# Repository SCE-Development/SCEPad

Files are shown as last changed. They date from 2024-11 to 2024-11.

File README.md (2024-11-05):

<p align="center" style = "font-size:48px;" >SCEPad</p>

<div align="center"

[]()
[]()
[]()
[]()
[]()

</div>

## General Description 
The SCE Pad is a instructional tool used during our soldering workshop series.

## Table of Contents
- Bill of Materials
- Firmware Flashing
- Assembly Instructions 

## Bill of Materials
| Qty | Item | Notes
| ---- | ---- | ---- |
| 1 | Arduino Pro Micro (ATmega32u4) | Alternatively you can use the [Elite-C](https://keeb.io/products/elite-c-low-profile-version-usb-c-pro-micro-replacement-atmega32u4) or [Nice!Nano](https://nicekeyboards.com/nice-nano/)|
| 18  | Cherry MX compatible swtiches | |
| 18  | SOD-123 1N4148/1N4148W diodes | |
| 18  | Kailh PCB sockets CPG151101S11 | |
| 9 | WS2812B RGB LEDs | |
| 9 | SMD 0805 100nF capacitors | |
| 1 | I2C 0.91" 128\*32 OLED Display Module | The ones using SSD1306 driver IC over I2C |
| 1 | 6mm\*6mm button switch | |
| 1 | SCEPad PCB | Available in SCE Club Room (ENG294) |
| 5 | M3 screws | |

## Firmware Flashing

Requirements
- [QMK Toolbox](https://github.com/qmk/qmk_toolbox)

After installing QMK toolbox, assuming you are using the default ProMicro controller, plug the device into your computer and you should see it show up as a new device in the console. Make sure the MCU selected is an ATmega32U4. Auto-flash is useful here but its preference. 

Select your hex-file and flash your microcontroller.

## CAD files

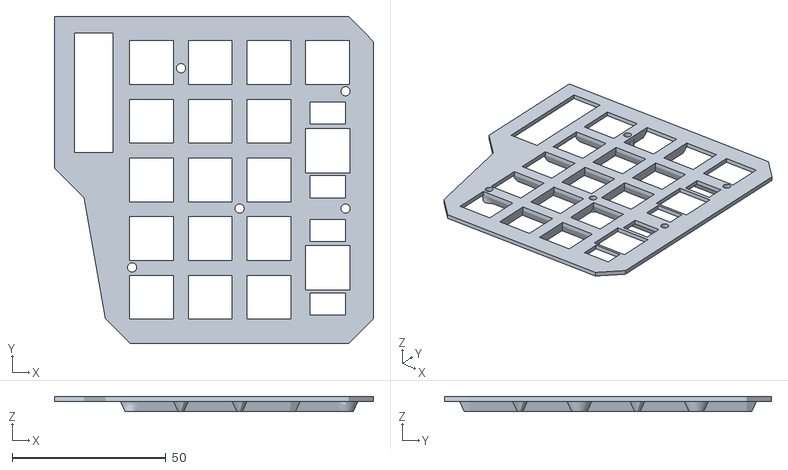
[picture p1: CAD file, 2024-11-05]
Case/SCEPAD Mounting Plate.stl
103.6 x 106.2 x 4.80

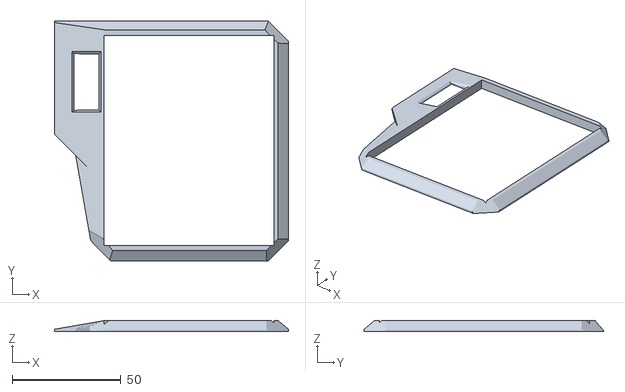
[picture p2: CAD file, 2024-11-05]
Case/SCEPAD Top Plate.stl
107.4 x 110.0 x 5.00

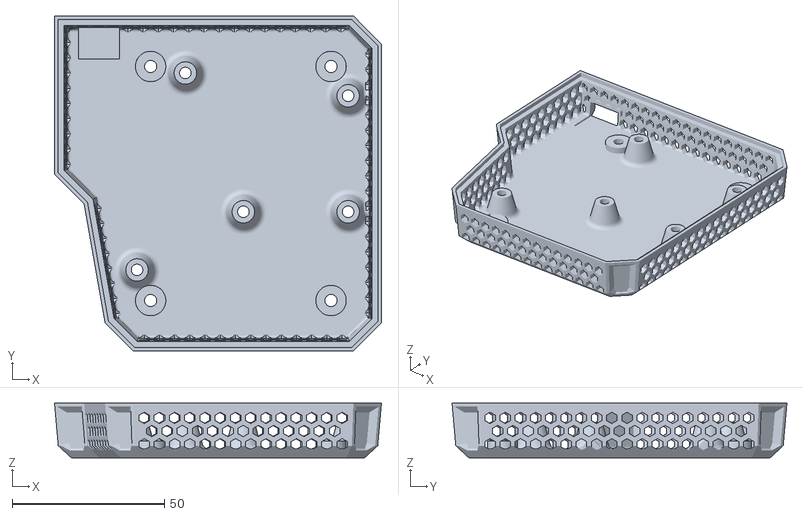
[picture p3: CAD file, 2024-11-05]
Case/SCEPAD Number Pad.stl
107.4 x 110.0 x 18.0

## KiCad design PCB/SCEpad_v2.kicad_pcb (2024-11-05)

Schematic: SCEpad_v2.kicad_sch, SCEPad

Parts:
C0, C1, C2, C3, C4, C5, C6, C7, C8: 104; C_0805_2012Metric_Pad1.15x1.40mm_HandSolder
D0, D1, D2, D3, D10, D11, D12, D13, D20, D21, D22, D30, D31, D32, D40, D41, D42, D43: D; D_SOD123_axial-dual
JOLED1: Conn_01x04; PinHeader_1x04_P2.54mm_Horizontal
K0, K1, K2, K3, K10, K11, K12, K13, K20, K21, K22, K30, K31, K32, K40, K41, K42, K43: KEYSW; Kailh-PCB-Socket-1U-Cutout
LED0, LED1, LED2, LED3, LED4, LED5, LED6, LED7, LED8: WS2812B; LED_WS2812B_PLCC4_5.0x5.0mm_P3.2mm
SW0: SW_Push; SW_PUSH_6mm
U0: ProMicro; ArduinoProMicro

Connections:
COL0: K0.1, K10.1, K20.1, K30.1, K40.1, U0.16
COL1: K1.1, K11.1, K21.1, K31.1, K41.1, U0.15
COL2: K2.1, K12.1, K22.1, K32.1, K42.1, U0.14
COL3: K3.1, K13.1, K43.1, U0.13
GND: C0.1, C1.1, C2.1, C3.1, C4.1, C5.1, C6.1, C7.1, C8.1, JOLED1.4, LED0.3 (VSS), LED1.3 (VSS), LED2.3 (VSS), LED3.3 (VSS), LED4.3 (VSS), LED5.3 (VSS), LED6.3 (VSS), LED7.3 (VSS), LED8.3 (VSS), SW0.1, U0.3, U0.4, U0.23; also elsewhere on the board
LEDs: LED0.4 (DIN), U0.20
unnamed: D0.2 (A), K0.2
unnamed: D1.2 (A), K1.2
unnamed: D2.2 (A), K2.2
unnamed: D3.2 (A), K3.2
unnamed: D10.2 (A), K10.2
unnamed: D11.2 (A), K11.2
unnamed: D12.2 (A), K12.2
unnamed: D13.2 (A), K13.2
unnamed: D20.2 (A), K20.2
unnamed: D21.2 (A), K21.2
unnamed: D22.2 (A), K22.2
unnamed: D30.2 (A), K30.2
unnamed: D31.2 (A), K31.2
unnamed: D32.2 (A), K32.2
unnamed: D40.2 (A), K40.2
unnamed: D41.2 (A), K41.2
unnamed: D42.2 (A), K42.2
unnamed: D43.2 (A), K43.2
unnamed: LED0.2 (DOUT), LED1.4 (DIN)
unnamed: LED1.2 (DOUT), LED2.4 (DIN)
unnamed: LED2.2 (DOUT), LED3.4 (DIN)
unnamed: LED3.2 (DOUT), LED4.4 (DIN)
unnamed: LED4.2 (DOUT), LED5.4 (DIN)
unnamed: LED5.2 (DOUT), LED6.4 (DIN)
unnamed: LED6.2 (DOUT), LED7.4 (DIN)
unnamed: LED7.2 (DOUT), LED8.4 (DIN)
PF7: U0.17
ROW0: D0.1 (K), D1.1 (K), D2.1 (K), D3.1 (K), U0.8
ROW1: D10.1 (K), D11.1 (K), D12.1 (K), D13.1 (K), U0.9
ROW2: D20.1 (K), D21.1 (K), D22.1 (K), U0.10
ROW3: D30.1 (K), D31.1 (K), D32.1 (K), U0.11
ROW4: D40.1 (K), D41.1 (K), D42.1 (K), D43.1 (K), U0.12
RST: U0.22; also elsewhere on the board
SCL: U0.6; also elsewhere on the board
SDA: U0.5; also elsewhere on the board
VCC: C0.2, C1.2, C2.2, C3.2, C4.2, C5.2, C6.2, C7.2, C8.2, JOLED1.3, LED0.1 (VDD), LED1.1 (VDD), LED2.1 (VDD), LED3.1 (VDD), LED4.1 (VDD), LED5.1 (VDD), LED6.1 (VDD), LED7.1 (VDD), LED8.1 (VDD), U0.21; also elsewhere on the board

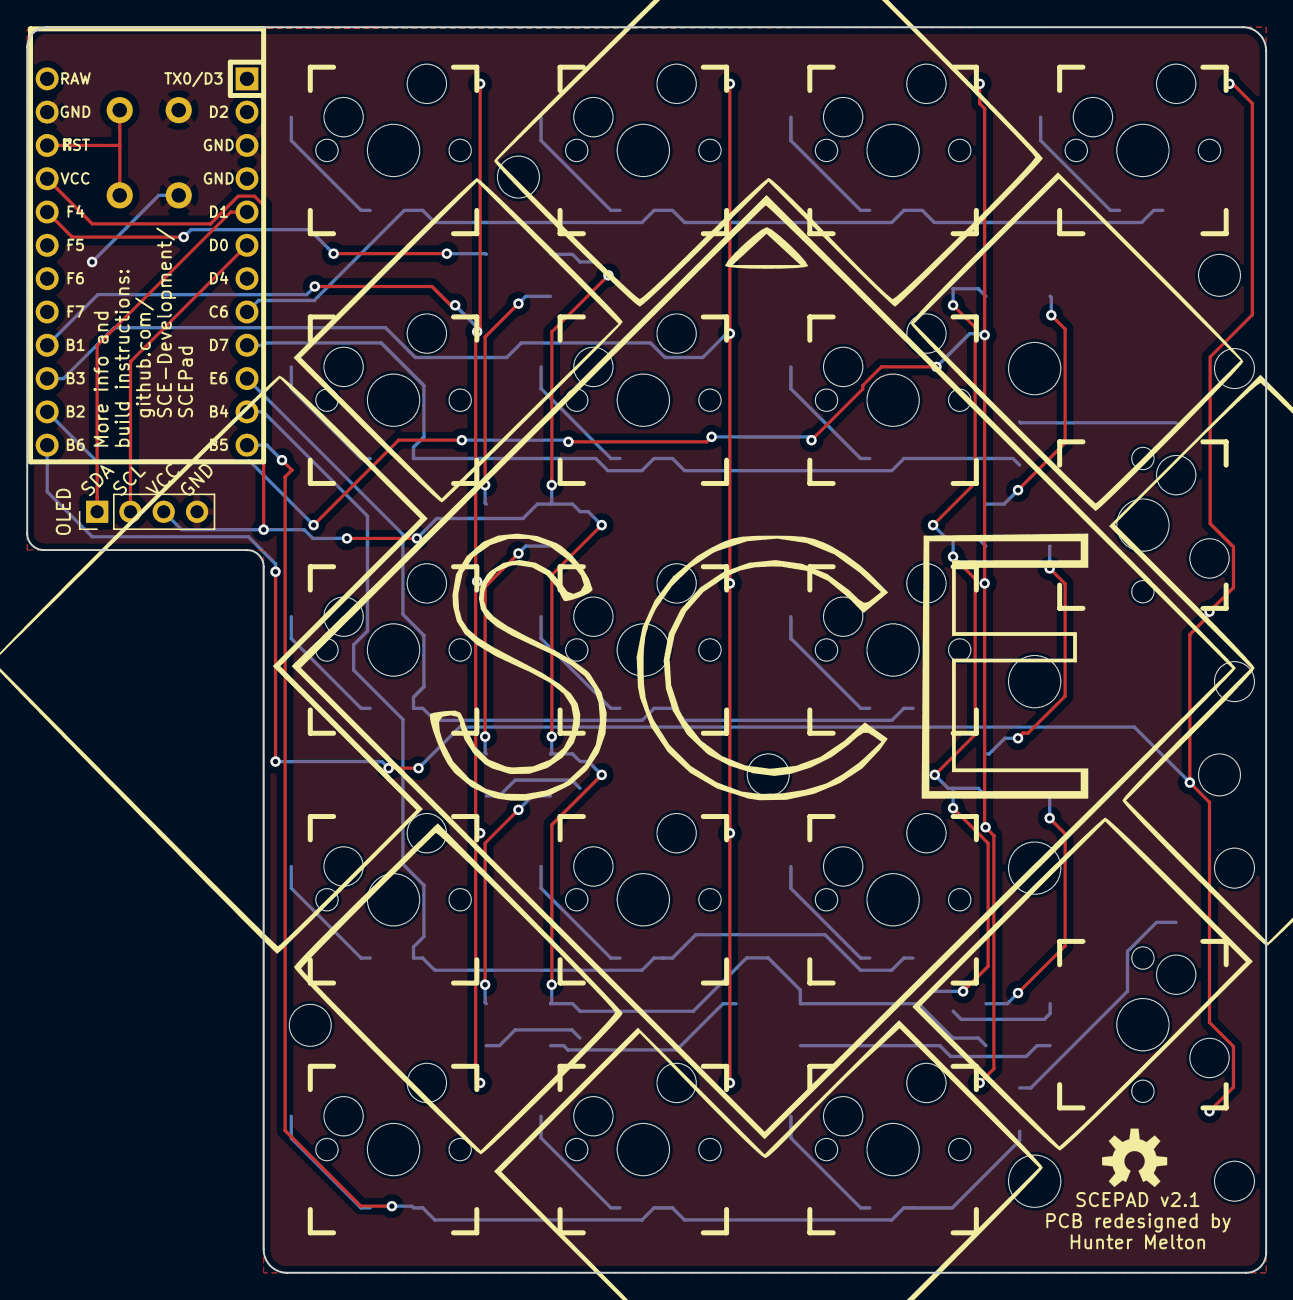
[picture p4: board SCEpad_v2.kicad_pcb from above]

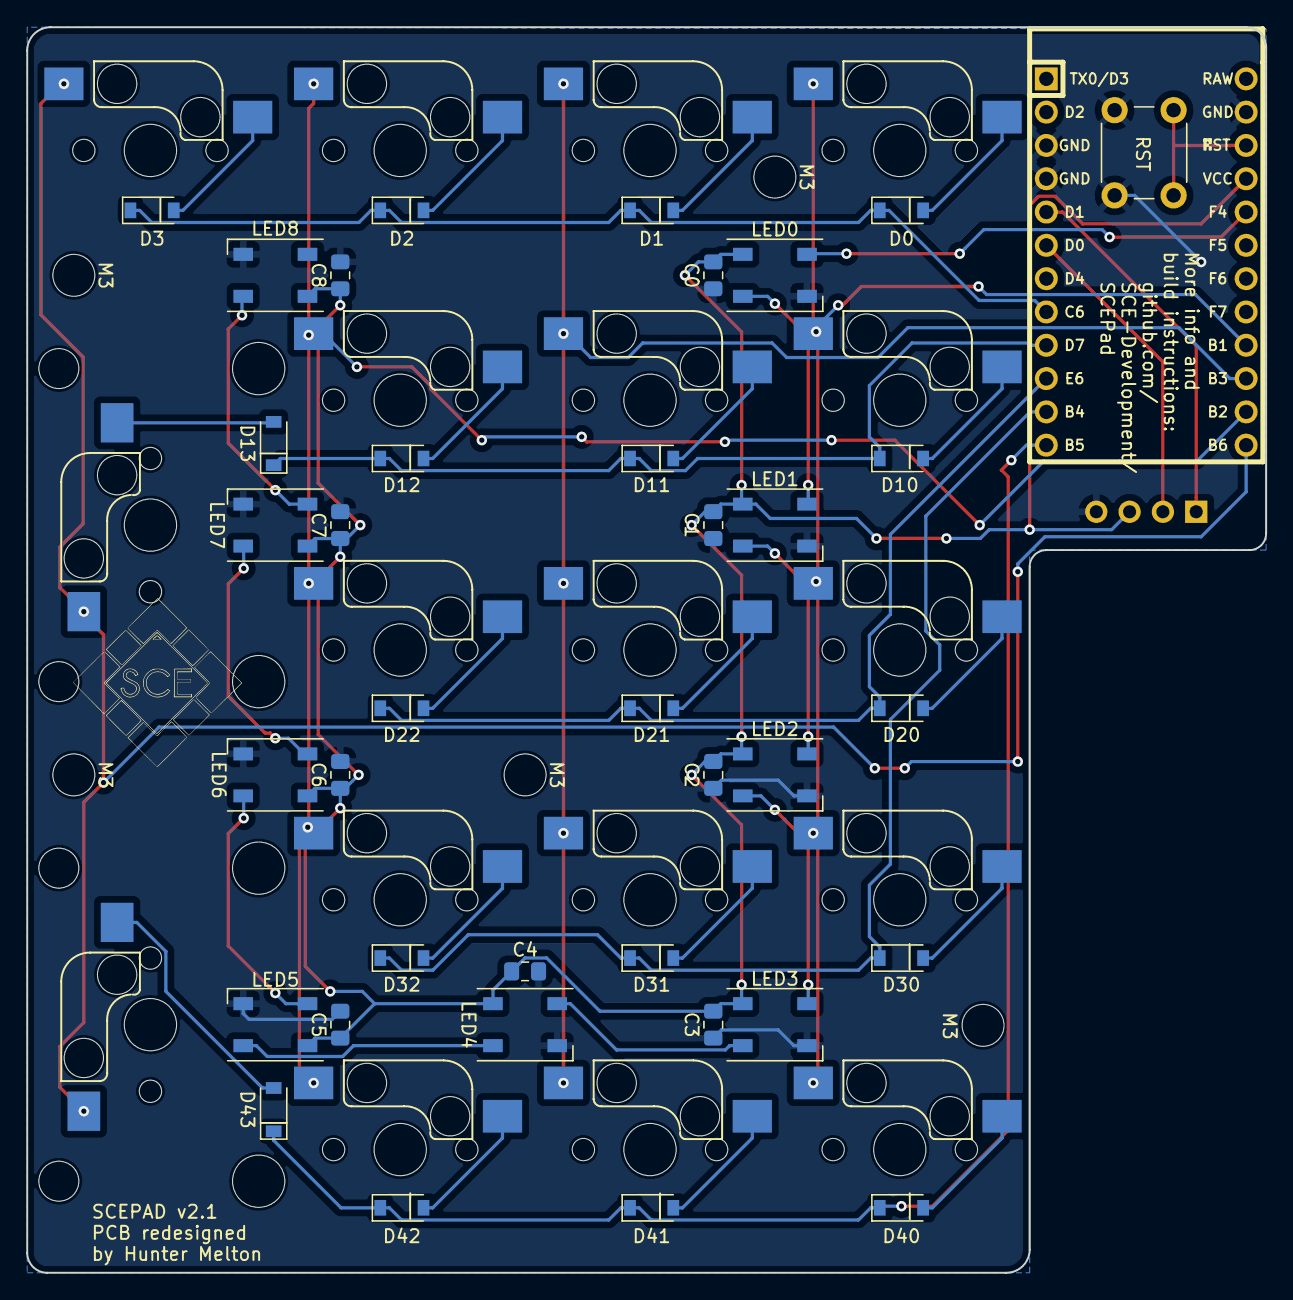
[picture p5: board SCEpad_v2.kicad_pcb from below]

Board: 2 copper layers, 94.5 x 95.0 mm, 62 parts (43 on the bottom side), 41 nets.

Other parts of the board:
M3, M3#2, M3#3, M3#4, M3#5: MountingHole_3.2mm_M3
OLED: Conn_01x04; PinHeader_1x04_P2.54mm_Vertical
RST: SW_Push; SW_PUSH_6mm

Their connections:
GND: OLED.4, RST.1; also elsewhere on the board
RST: RST.2; also elsewhere on the board
SCL: OLED.2; also elsewhere on the board
SDA: OLED.1; also elsewhere on the board
VCC: OLED.3; also elsewhere on the board

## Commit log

2024-11-05 Case Files
    [SCEPAD Mounting Plate.stl, SCEPAD Number Pad.stl, SCEPAD Top Plate.stl]
2024-11-05 PCB Gerber Files
2024-11-05 KiCad Project File & PCB files
    [SCEpad_v2.kicad_pcb, SCEpad_v2.kicad_sch, SCEpad_v2.sch]
